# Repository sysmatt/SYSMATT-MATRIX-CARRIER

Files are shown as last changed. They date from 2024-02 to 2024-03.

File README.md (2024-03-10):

# SYSMATT-MATRIX-CARRIER
## An all-pcb combined ESB32 based WS2812B matrix carrier and diffuser.

### ... It's a sandwich. 

If you end up building these, please tag me on social media... @SYSMATT on X/Twitter - TY!

These cheap pre-made WS2812B flexible matrix boards are plentiful and availible on Amazon/Aliexpress/etc.  

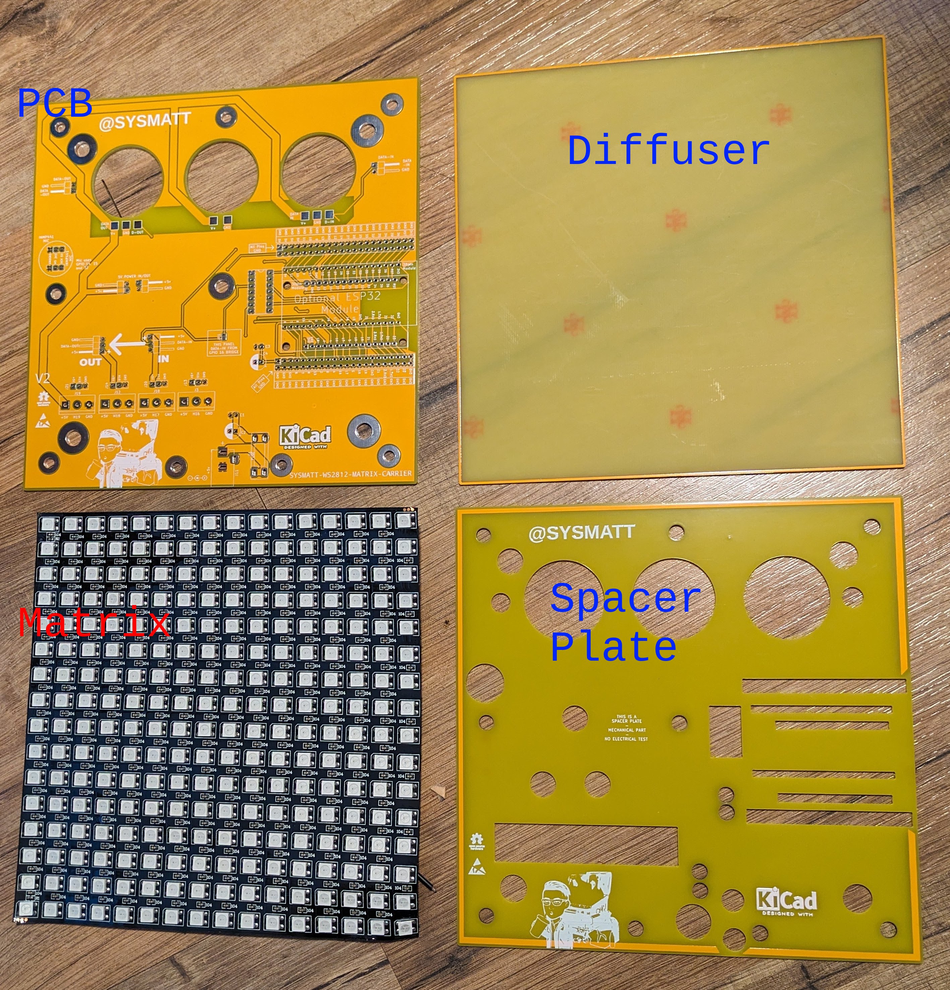
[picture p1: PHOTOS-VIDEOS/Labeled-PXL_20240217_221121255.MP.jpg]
Labeled photo of PCBs


They look great through a 1mm FR4 PCB diffuser. 

In this repo is the carrier board I created to control them with the common 30pin or 38pin ESP32 WROOM modules.  

It supports WLED easily, and even has suport for audio reactive WLED using the common 6-pin INMP441 digital microphone modules.

The boards are assembled in a sandwich,  The main electronics PCB with the ESP module, Mic module, A SN74AHCT125N used as a voltage translator, and an assortment of connector options for input/output.

The boards can be assembled "smart" (With an ESP) ... or "dumb"... where it will be chained from a smart board. 

Four ESP outputs are voltage level translated in total to allow you to create large matrix displays. 

There is also a fuse.  Because house fires are no joke. 

Designed using through hole because I have a pile of parts (Im a parts hoarder) ... And the are super easy for most people. 

I will add more here when I have time.  There are videos on the PHOTOS-VIDEOS directory.  Also on youtube:

Video link to YouTube:
Video (https://www.youtube.com/watch?v=TLycWf7s_p8)

https://youtube.com/shorts/75FGs6rpeio

https://youtube.com/shorts/8wDof0Con4Y

https://youtube.com/shorts/0d_V_7tXByc

https://www.youtube.com/watch?v=TLycWf7s_p8

Iamge of the 16x16 board

Iamge of the 16x16 board

Iamge of the 16x16 boards, unassembled

Iamge of the 16x16 boards, It's a SANDWICH

Iamge of the 32x8 board, unassembled

Iamge of the 16x16 board
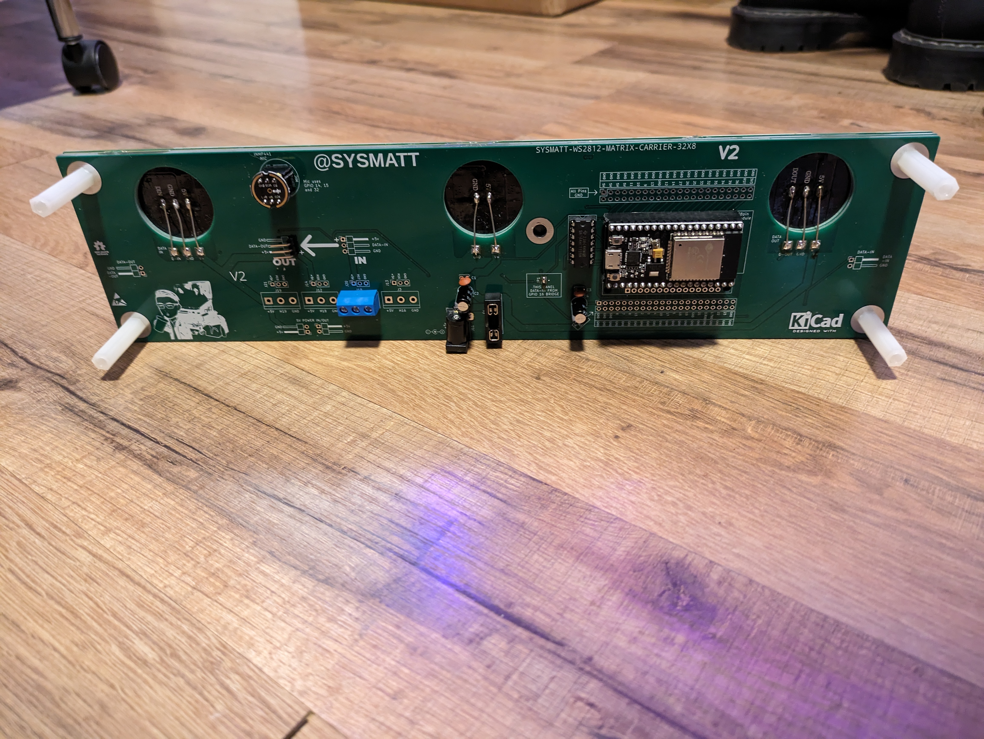
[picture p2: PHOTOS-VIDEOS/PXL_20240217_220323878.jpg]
Iamge of the 16x16 board


I just use a couplle dots of silicone to hold the sandwitch together 

Iamge of the 16x16 DUMB board, Being glued up
Iamge of the 16x16 DUMB board, Being glued up

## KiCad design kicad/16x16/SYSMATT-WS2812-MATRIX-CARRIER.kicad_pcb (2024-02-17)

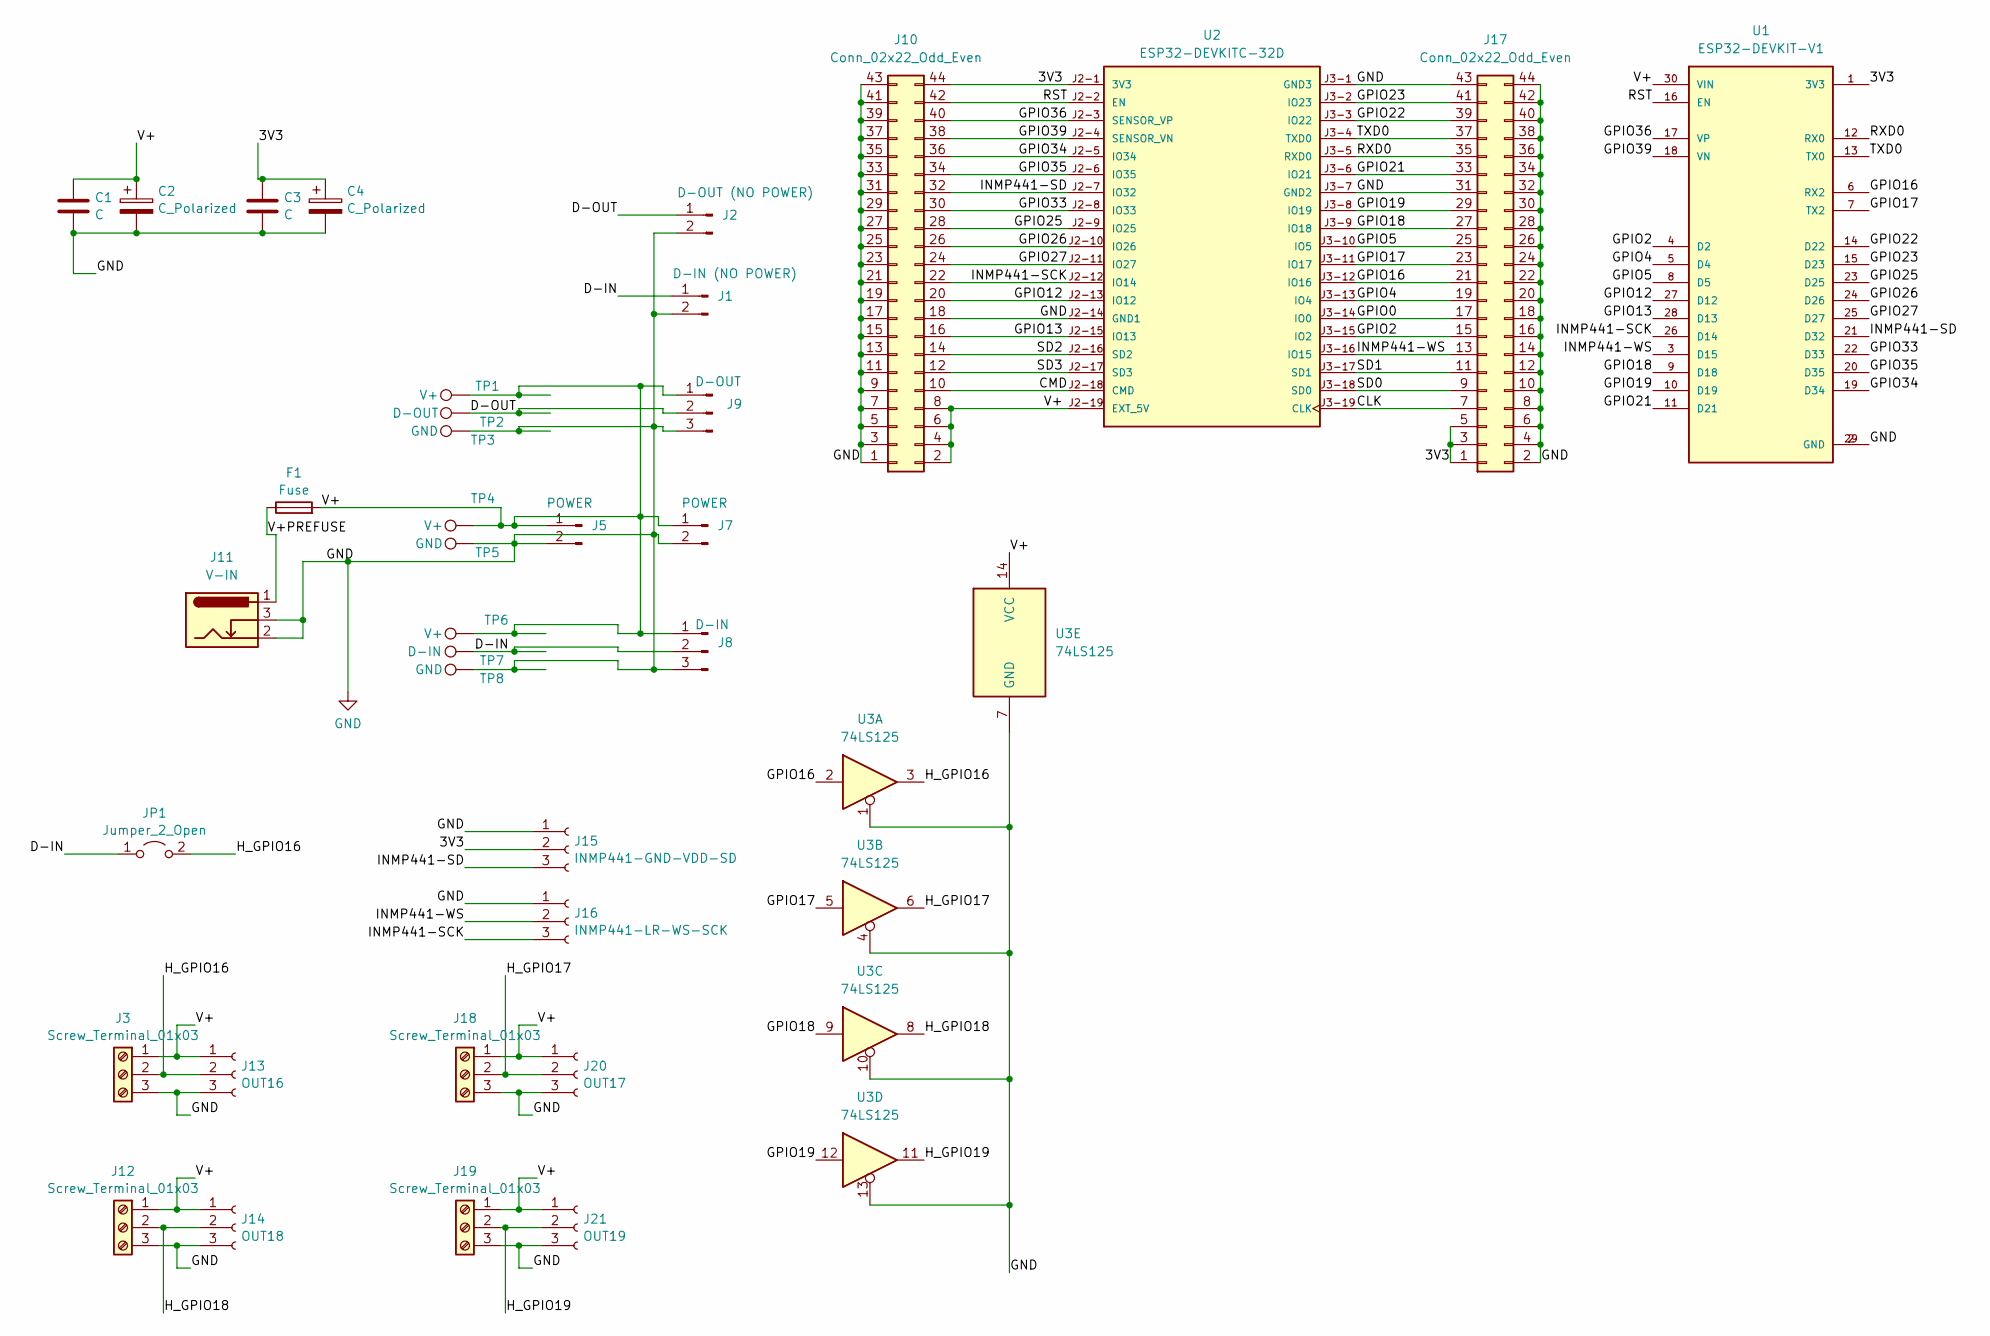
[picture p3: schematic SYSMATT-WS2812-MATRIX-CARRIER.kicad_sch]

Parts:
C1, C3: C; C_Disc_D3.8mm_W2.6mm_P2.50mm
C2, C4: C_Polarized; CP_Radial_D6.3mm_P2.50mm
F1: Fuse; Ebay-Fuse-holder-04mmX15mm-black-auto-fuse-dingus
J1: D-IN (NO POWER); PinHeader_1x02_P2.54mm_Horizontal
J2: D-OUT (NO POWER); PinHeader_1x02_P2.54mm_Horizontal
J3, J12, J18, J19: Screw_Terminal_01x03; TerminalBlock_bornier-3_P5.08mm
J5, J7: POWER; PinHeader_1x02_P2.54mm_Horizontal
J8: D-IN; PinHeader_1x03_P2.54mm_Horizontal
J9: D-OUT; PinHeader_1x03_P2.54mm_Horizontal
J10, J17: Conn_02x22_Odd_Even; PinSocket_2x22_P2.54mm_Vertical
J11: V-IN; BarrelJack_Horizontal
J13: OUT16; PinSocket_1x03_P2.54mm_Vertical
J14: OUT18; PinSocket_1x03_P2.54mm_Vertical
J15: INMP441-GND-VDD-SD; PinSocket_1x03_P2.54mm_Vertical
J16: INMP441-LR-WS-SCK; PinSocket_1x03_P2.54mm_Vertical
J20: OUT17; PinSocket_1x03_P2.54mm_Vertical
J21: OUT19; PinSocket_1x03_P2.54mm_Vertical
JP1: Jumper_2_Open; SolderJumper-2_P1.3mm_Open_TrianglePad1.0x1.5mm
TP1, TP4, TP6: V+; TestPoint_Pad_3.0x3.0mm
TP2: D-OUT; TestPoint_Pad_3.0x3.0mm
TP3, TP5, TP8: GND; TestPoint_Pad_3.0x3.0mm
TP7: D-IN; TestPoint_Pad_3.0x3.0mm
U1: ESP32-DEVKIT-V1; MODULE_ESP32_DEVKIT_V1-no-ant-keepout; PARTREV N/A
U2: ESP32-DEVKITC-32D; MODULE_ESP32-DEVKITC-32D-CORRECTED-WIDTH-NARROW; PARTREV V4
U3: 74LS125; DIP-14_W7.62mm_Socket_LongPads

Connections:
/3V3: C3.1, C4.1, J10.44, J15.2, J17.1, J17.3, J17.5, U1.1 (3V3), U2.J2-1 (3V3)
/CLK: J17.7, U2.J3-19 (CLK)
/CMD: J10.10, U2.J2-18 (CMD)
/D-IN: J1.1, J8.2, JP1.1 (A), TP7.1
/D-OUT: J2.1, J9.2, TP2.1
/GPIO0: J17.17, U2.J3-14 (IO0)
/GPIO2: J17.15, U1.4 (D2), U2.J3-15 (IO2)
/GPIO4: J17.19, U1.5 (D4), U2.J3-13 (IO4)
/GPIO5: J17.25, U1.8 (D5), U2.J3-10 (IO5)
/GPIO12: J10.20, U1.27 (D12), U2.J2-13 (IO12)
/GPIO13: J10.16, U1.28 (D13), U2.J2-15 (IO13)
/GPIO16: J17.21, U1.6 (RX2), U2.J3-12 (IO16), U3.2
/GPIO17: J17.23, U1.7 (TX2), U2.J3-11 (IO17), U3.5
/GPIO18: J17.27, U1.9 (D18), U2.J3-9 (IO18), U3.9
/GPIO19: J17.29, U1.10 (D19), U2.J3-8 (IO19), U3.12
/GPIO21: J17.33, U1.11 (D21), U2.J3-6 (IO21)
/GPIO22: J17.39, U1.14 (D22), U2.J3-3 (IO22)
/GPIO23: J17.41, U1.15 (D23), U2.J3-2 (IO23)
/GPIO25: J10.28, U1.23 (D25), U2.J2-9 (IO25)
/GPIO26: J10.26, U1.24 (D26), U2.J2-10 (IO26)
/GPIO27: J10.24, U1.25 (D27), U2.J2-11 (IO27)
/GPIO33: J10.30, U1.22 (D33), U2.J2-8 (IO33)
/GPIO34: J10.36, U1.19 (D34), U2.J2-5 (IO34)
/GPIO35: J10.34, U1.20 (D35), U2.J2-6 (IO35)
/GPIO36: J10.40, U1.17 (VP), U2.J2-3 (SENSOR_VP)
/GPIO39: J10.38, U1.18 (VN), U2.J2-4 (SENSOR_VN)
/H_GPIO16: J3.2, J13.2, JP1.2 (B), U3.3
/H_GPIO17: J18.2, J20.2, U3.6
/H_GPIO18: J12.2, J14.2, U3.8
/H_GPIO19: J19.2, J21.2, U3.11
/INMP441-SCK: J10.22, J16.3, U1.26 (D14), U2.J2-12 (IO14)
/INMP441-SD: J10.32, J15.3, U1.21 (D32), U2.J2-7 (IO32)
/INMP441-WS: J16.2, J17.13, U1.3 (D15), U2.J3-16 (IO15)
/RST: J10.42, U1.16 (EN), U2.J2-2 (EN)
/RXD0: J17.35, U1.12 (RX0), U2.J3-5 (RXD0)
/SD0: J17.9, U2.J3-18 (SD0)
/SD1: J17.11, U2.J3-17 (SD1)
/SD2: J10.14, U2.J2-16 (SD2)
/SD3: J10.12, U2.J2-17 (SD3)
/TXD0: J17.37, U1.13 (TX0), U2.J3-4 (TXD0)
/V+: C1.1, C2.1, F1.2, J3.1, J5.1, J7.1, J8.1, J9.1, J10.2, J10.4, J10.6, J10.8, J12.1, J13.1, J14.1, J18.1, J19.1, J20.1, J21.1, TP1.1, TP4.1, TP6.1, U1.30 (VIN), U2.J2-19 (EXT_5V), U3.14 (VCC)
/V+PREFUSE: F1.1, J11.1
GND: C1.2, C2.2, C3.2, C4.2, J1.2, J2.2, J3.3, J5.2, J7.2, J8.3, J9.3, J10.1, J10.3, J10.5, J10.7, J10.9, J10.11, J10.13, J10.15, J10.17, J10.18, J10.19, J10.21, J10.23, J10.25, J10.27, J10.29, J10.31, J10.33, J10.35, J10.37, J10.39, J10.41, J10.43, J11.2, J11.3, J12.3, J13.3, J14.3, J15.1, J16.1, J17.2, J17.4, J17.6, J17.8, J17.10, J17.12, J17.14, J17.16, J17.18, J17.20, J17.22, J17.24, J17.26, J17.28, J17.30, J17.31, J17.32, J17.34, J17.36, J17.38, J17.40, J17.42, J17.43, J17.44, J18.3, J19.3, J20.3, J21.3, TP3.1, TP5.1, TP8.1, U1.2 (GND), U1.29 (GND), U2.J2-14 (GND1), U2.J3-1 (GND3), U2.J3-7 (GND2), U3.1, U3.4, U3.7 (GND), U3.10, U3.13

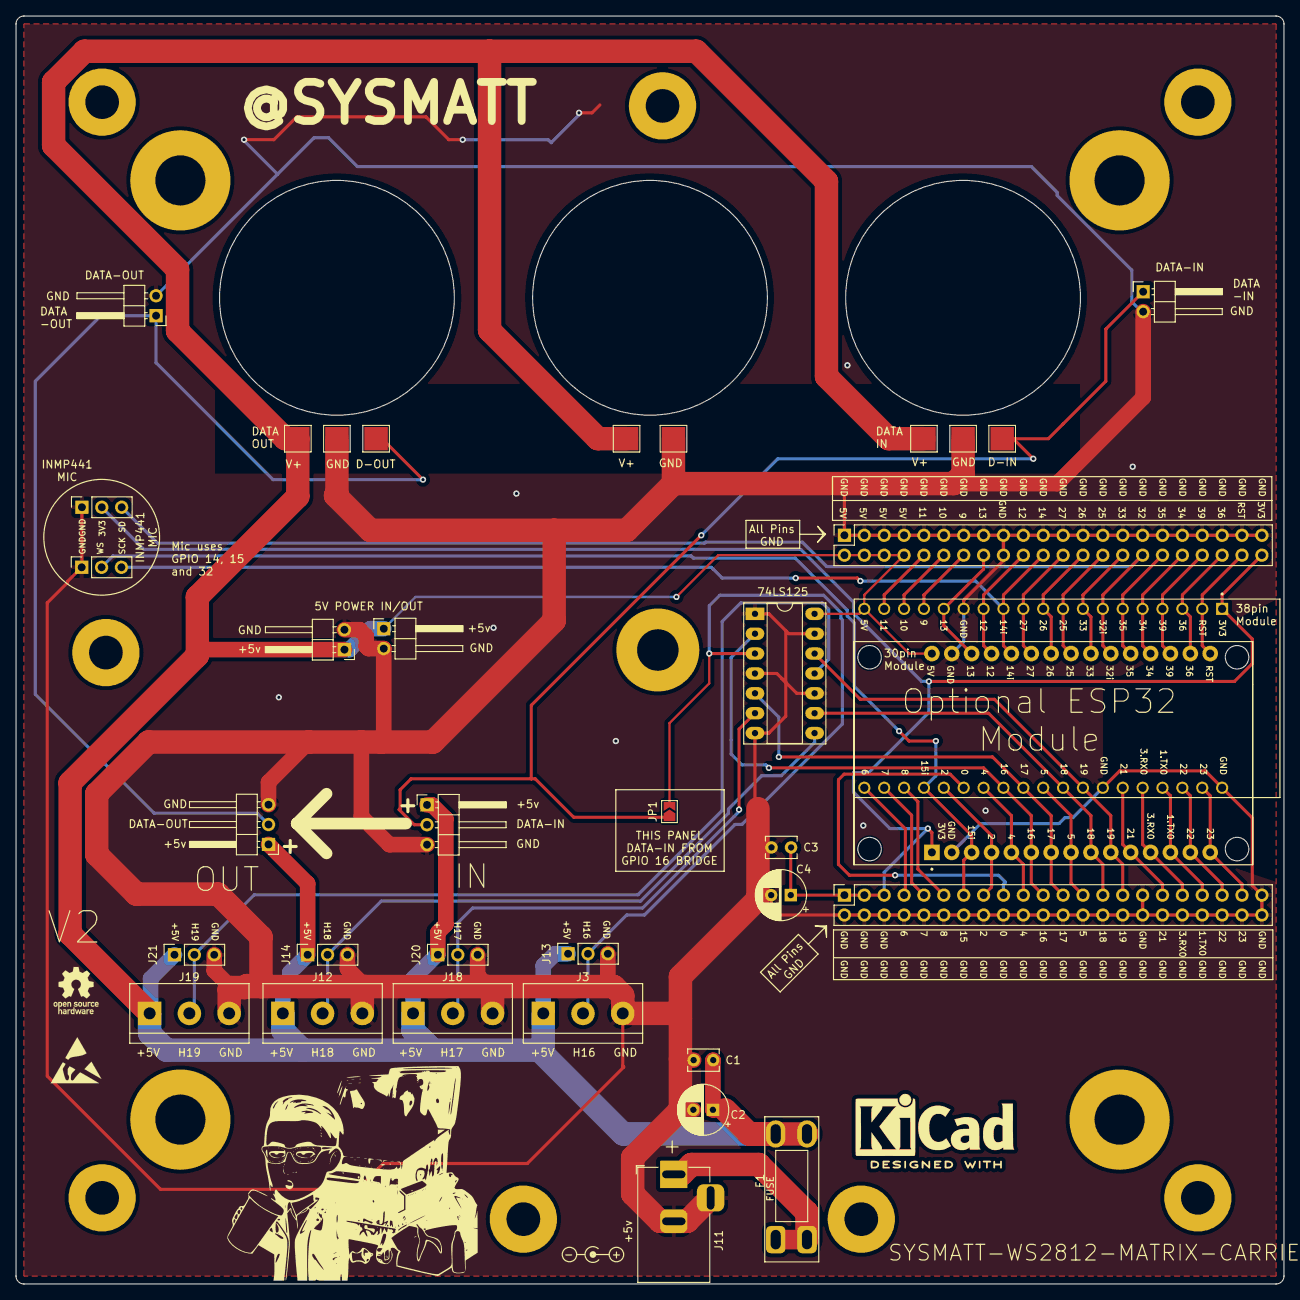
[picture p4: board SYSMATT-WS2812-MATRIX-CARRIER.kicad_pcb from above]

Board: 2 copper layers, 162.0 x 162.0 mm, 36 parts (0 on the bottom side), 43 nets.

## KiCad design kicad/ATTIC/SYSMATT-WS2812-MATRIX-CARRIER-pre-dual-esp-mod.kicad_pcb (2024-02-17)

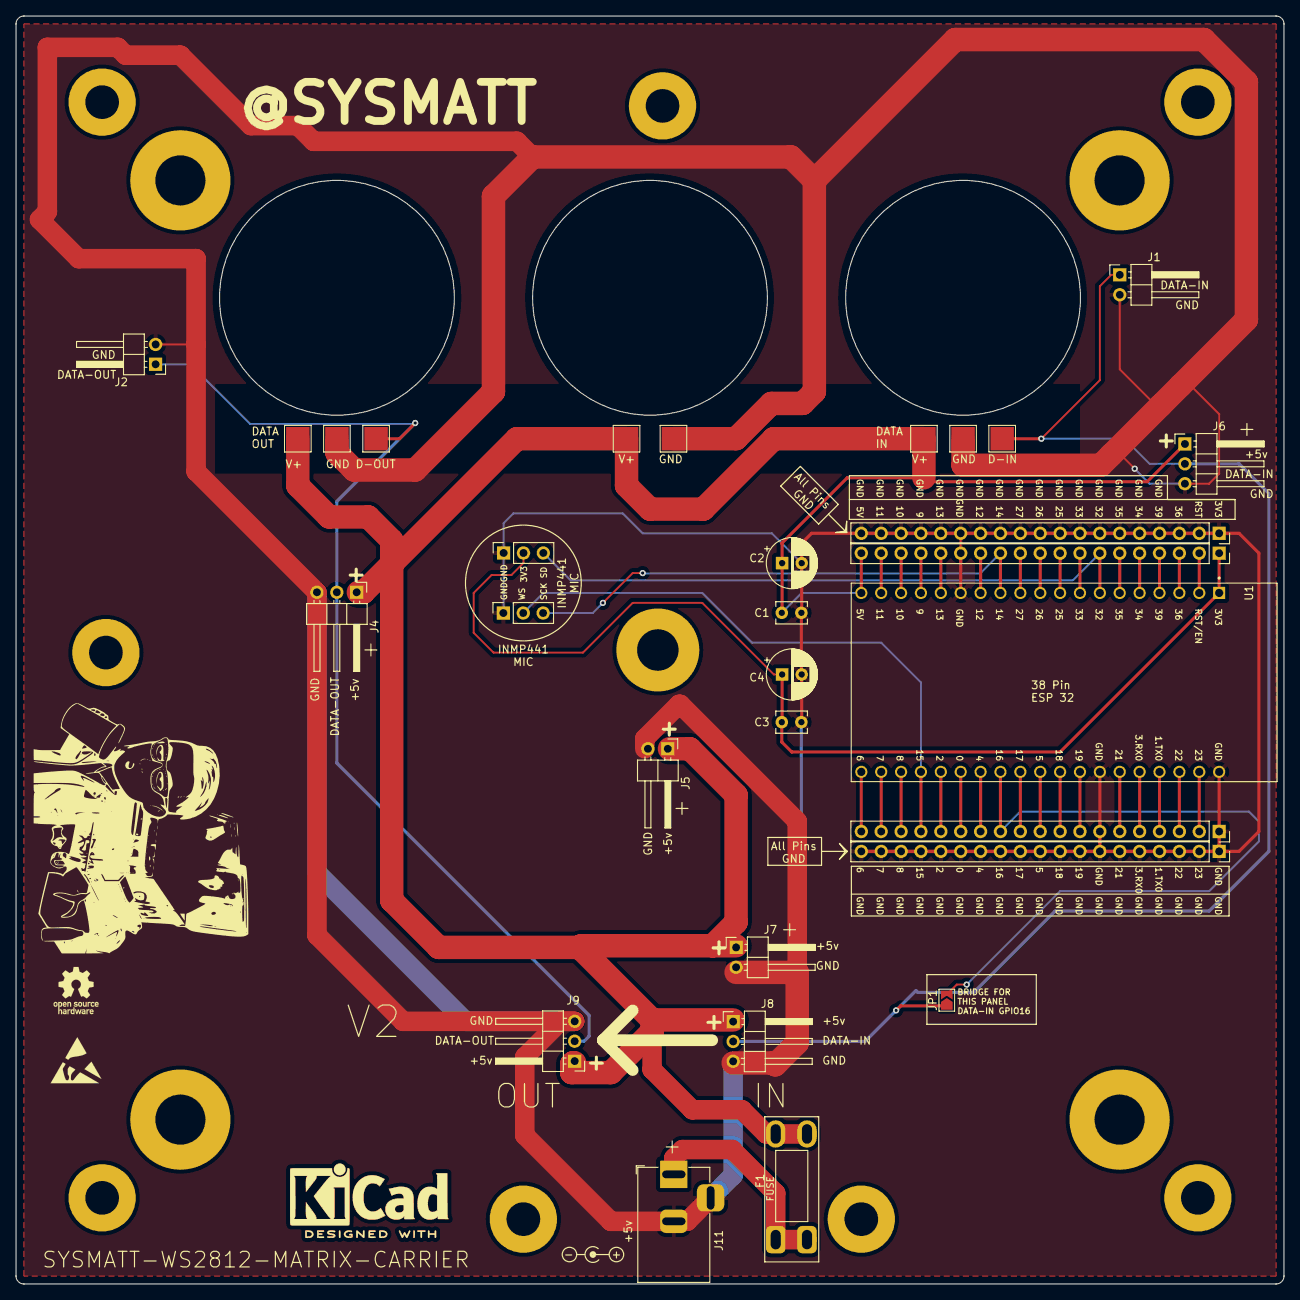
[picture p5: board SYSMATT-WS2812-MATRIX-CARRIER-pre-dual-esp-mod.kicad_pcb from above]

Board: 2 copper layers, 162.0 x 162.0 mm, 30 parts (0 on the bottom side), 39 nets.

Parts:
C1, C3: C; C_Disc_D3.8mm_W2.6mm_P2.50mm
C2, C4: C_Polarized; CP_Radial_D6.3mm_P2.50mm
F1: Fuse; Ebay-Fuse-holder-04mmX15mm-black-auto-fuse-dingus
J1: D-IN (NO POWER); PinHeader_1x02_P2.54mm_Horizontal
J2: D-OUT (NO POWER); PinHeader_1x02_P2.54mm_Horizontal
J3, J12, J13, J14: Conn_01x19_Pin; PinSocket_1x19_P2.54mm_Vertical
J4, J9: D-OUT; PinHeader_1x03_P2.54mm_Horizontal
J5, J7: POWER; PinHeader_1x02_P2.54mm_Horizontal
J6, J8: D-IN; PinHeader_1x03_P2.54mm_Horizontal
J11: V-IN; BarrelJack_Horizontal
J15: INMP441-GND-VDD-SD; PinSocket_1x03_P2.54mm_Vertical
J16: INMP441-LR-WS-SCK; PinSocket_1x03_P2.54mm_Vertical
JP1: Jumper_2_Open; SolderJumper-2_P1.3mm_Open_TrianglePad1.0x1.5mm
TP1, TP4, TP6: V+; TestPoint_Pad_3.0x3.0mm
TP2: D-OUT; TestPoint_Pad_3.0x3.0mm
TP3, TP5, TP8: GND; TestPoint_Pad_3.0x3.0mm
TP7: D-IN; TestPoint_Pad_3.0x3.0mm
U1: ESP32-DEVKITC-32D; MODULE_ESP32-DEVKITC-32D-CORRECTED-WIDTH-NARROW

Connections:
/3V3: C3.1, C4.1, J3.1, J15.2, U1.J2-1 (3V3)
/D-IN: J1.1, J6.2, J8.2, JP1.1 (A), TP7.1
/D-OUT: J2.1, J4.2, J9.2, TP2.1
/INMP441-SCK: J3.12, J16.3, U1.J2-12 (IO14)
/INMP441-SD: J3.7, J15.3, U1.J2-7 (IO32)
/INMP441-WS: J12.16, J16.2, U1.J3-16 (IO15)
/IO16: J12.12, JP1.2 (B), U1.J3-12 (IO16)
/V+: C1.1, C2.1, F1.2, J3.19, J4.1, J5.1, J6.1, J7.1, J8.1, J9.1, TP1.1, TP4.1, TP6.1, U1.J2-19 (EXT_5V)
/V+PREFUSE: F1.1, J11.1
GND: C1.2, C2.2, C3.2, C4.2, J1.2, J2.2, J3.14, J4.3, J5.2, J6.3, J7.2, J8.3, J9.3, J11.2, J11.3, J12.1, J12.7, J13.1, J13.2, J13.3, J13.4, J13.5, J13.6, J13.7, J13.8, J13.9, J13.10, J13.11, J13.12, J13.13, J13.14, J13.15, J13.16, J13.17, J13.18, J13.19, J14.1, J14.2, J14.3, J14.4, J14.5, J14.6, J14.7, J14.8, J14.9, J14.10, J14.11, J14.12, J14.13, J14.14, J14.15, J14.16, J14.17, J14.18, J14.19, J15.1, J16.1, TP3.1, TP5.1, TP8.1, U1.J2-14 (GND1), U1.J3-1 (GND3), U1.J3-7 (GND2)
unnamed: J3.2, U1.J2-2 (EN)
unnamed: J3.3, U1.J2-3 (SENSOR_VP)
unnamed: J3.4, U1.J2-4 (SENSOR_VN)
unnamed: J3.5, U1.J2-5 (IO34)
unnamed: J3.6, U1.J2-6 (IO35)
unnamed: J3.8, U1.J2-8 (IO33)
unnamed: J3.9, U1.J2-9 (IO25)
unnamed: J3.10, U1.J2-10 (IO26)
unnamed: J3.11, U1.J2-11 (IO27)
unnamed: J3.13, U1.J2-13 (IO12)
unnamed: J3.15, U1.J2-15 (IO13)
unnamed: J3.16, U1.J2-16 (SD2)
unnamed: J3.17, U1.J2-17 (SD3)
unnamed: J3.18, U1.J2-18 (CMD)
unnamed: J12.2, U1.J3-2 (IO23)
unnamed: J12.3, U1.J3-3 (IO22)
unnamed: J12.4, U1.J3-4 (TXD0)
unnamed: J12.5, U1.J3-5 (RXD0)
unnamed: J12.6, U1.J3-6 (IO21)
unnamed: J12.8, U1.J3-8 (IO19)
unnamed: J12.9, U1.J3-9 (IO18)
unnamed: J12.10, U1.J3-10 (IO5)
unnamed: J12.11, U1.J3-11 (IO17)
unnamed: J12.13, U1.J3-13 (IO4)
unnamed: J12.14, U1.J3-14 (IO0)
unnamed: J12.15, U1.J3-15 (IO2)
unnamed: J12.17, U1.J3-17 (SD1)
unnamed: J12.18, U1.J3-18 (SD0)
unnamed: J12.19, U1.J3-19 (CLK)
